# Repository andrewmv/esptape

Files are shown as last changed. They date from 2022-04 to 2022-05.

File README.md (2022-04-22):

An ESPHome based Home Assistant integration for controlling a Sony TC-WE675 Tape deck over its A1 Control serial port.

Would probably work on other Sony A1 tape decks, and could likely be expanded to support other Sony A1 audio equipment.

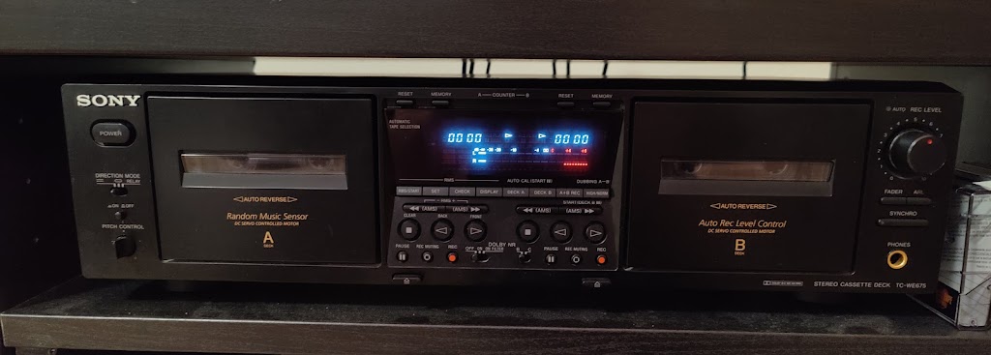
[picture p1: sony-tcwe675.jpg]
sony-tcwe675


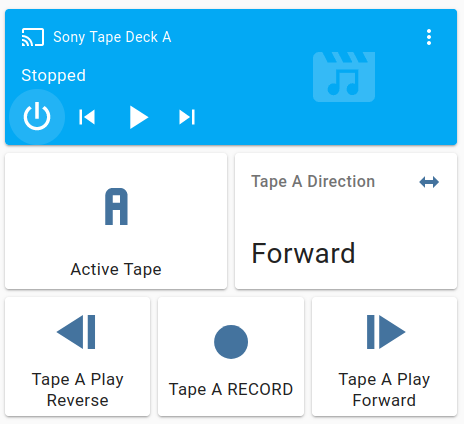
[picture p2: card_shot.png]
card_shot


## Repository Structure

* /esphome - esphome YAML code
* /homeassistant - sample HACS/media_player_template entity and lovelace cards
* /util - code timing conversion utilities
* /pcb - EagleCAD files for hardware build
* /enclosure - OpenSCAD and STL files for 3D printing enclosure

## Protocol 

Protocol based in part on the A1/S-Link reverse engineering work of:

http://cegt201.bradley.edu/projects/proj2001/sonyntwk/SLink.PDF

and:

http://web.archive.org/web/20040722145551/http://www.undeadscientist.com/slink/encoding.html

I created a PulseView / Sigrok logic analyizer plugin to aid in the discovery of device specific codes:

https://github.com/andrewmv/sony-a1-sigrok-pd

## Status Codes

Reported from the device and interpreted by ESPHome

| Address | Code | Meaning | Notes |
| --- | ---- | --- | --- |
| 0xAC | 0x00 | Tape B Play | No indication of direction is provided |
| 0xAC | 0x01 | Tape B Stop | |
| 0xAC | 0x02 | Tape B Pause | |
| 0xAC | 0x04 | Tape B Record | Recording started |
| 0xAC | 0x05 | Tape B Eject | |
| 0xAC | 0x06 | Tape B Autoreverse | Valid only from Play. Playback has reached end of side, but will continue on other side or deck. Always followed by a Stop, then a Play from the appropriate deck |
| 0xAC | 0x07 | Tape B Cue | |
| 0xAC | 0x08 | Tape B Insert | |
| 0xAC | 0x0a | End of Tape B | End of side reached, no followup playback will happen. Valid from Play, RR, FF, or AMS. |
| 0xAC | 0x40 | Tape A Play | No indication of direction is provided |
| 0xAC | 0x41 | Tape A Stop | |
| 0xAC | 0x42 | Tape A Pause | |
| 0xAC | 0x44 | Tape A Record | Recording started |
| 0xAC | 0x45 | Tape A Eject | |
| 0xAC | 0x46 | Tape A Autoreverse | Valid only from Play. Playback has reached end of side, but will continue on other side or deck. Always followed by a Stop, then a Play from the appropriate deck |
| 0xAC | 0x47 | Tape A Cue | Recording cued, play not yet pressed |
| 0xAC | 0x48 | Tape A Insert | |
| 0xAC | 0x4a | End of Tape A | End of side reached, no followup playback will happen. Valid from Play, RR, FF, or AMS. |

## Command codes

Sent to and interpreted by the device

| Address | Command | Result |
| --- | --- | --- |
| 0xA4 | 0x00 | Deck B Play (Current Direction) |
| 0xA4 | 0x01 | Deck B Stop |
| 0xA4 | 0x02 | Deck B Pause (Fixed) |
| 0xA4 | 0x03 | Deck B Pause (Toggle) |
| 0xA4 | 0x04 | Deck B Rec (Current Direction) |
| 0xA4 | 0x07 | Deck B Rec Cue (Direction Selectable with subsequent Play) |
| 0xA4 | 0x0A | Deck B FF (While Stopped – Forward) / AMS (While Playing – Current Direction) |
| 0xA4 | 0x0B | Deck B RR (While Stopped – Reverse) / AMS (While Playing – Current Direction) |
| 0xA4 | 0x0C | Deck B Play Forward |
| 0xA4 | 0x0D | Deck B Play Backward |
| 0xA4 | 0x40 | Deck A Play (Current Direction) |
| 0xA4 | 0x41 | Deck A Stop |
| 0xA4 | 0x42 | Deck A Pause (Fixed) |
| 0xA4 | 0x43 | Deck A Pause (Toggle) |
| 0xA4 | 0x44 | Deck A Rec (Current Direction) |
| 0xA4 | 0x47 | Deck A Rec Cue |
| 0xA4 | 0x4A | Deck A FF (While Stopped – Forward) / AMS (While Playing – Current Direction) |
| 0xA4 | 0x4B | Deck A RR (While Stopped – Rewind) / AMS (While Playing – Current Direction) |
| 0xA4 | 0x4C | Deck A Play Forward |
| 0xA4 | 0x4D | Deck A Play Backward |

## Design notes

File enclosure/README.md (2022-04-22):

OpenSCAD source files and rendered STLs for printable PCB enclosure.

Designed to use M2 x 3.5mm threaded brass inserts

## Print Settings

* Supports: no
* Infill: 100% where tape_enclosure and tape_enclosure_supports overlap, 20% everywhere else
* Material: any

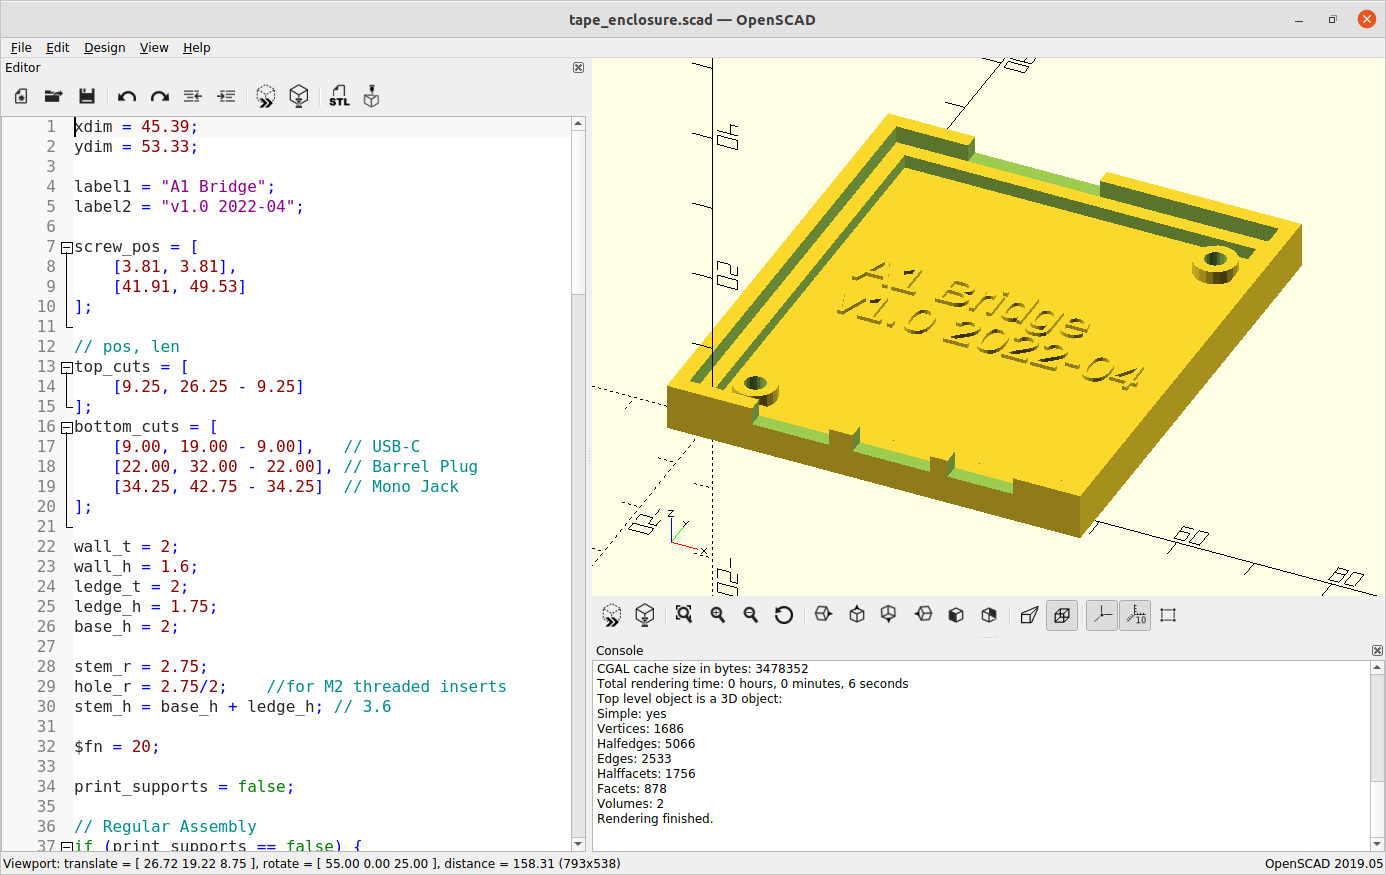
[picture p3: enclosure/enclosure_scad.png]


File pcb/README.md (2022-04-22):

Board and schematic files for EagleCAD

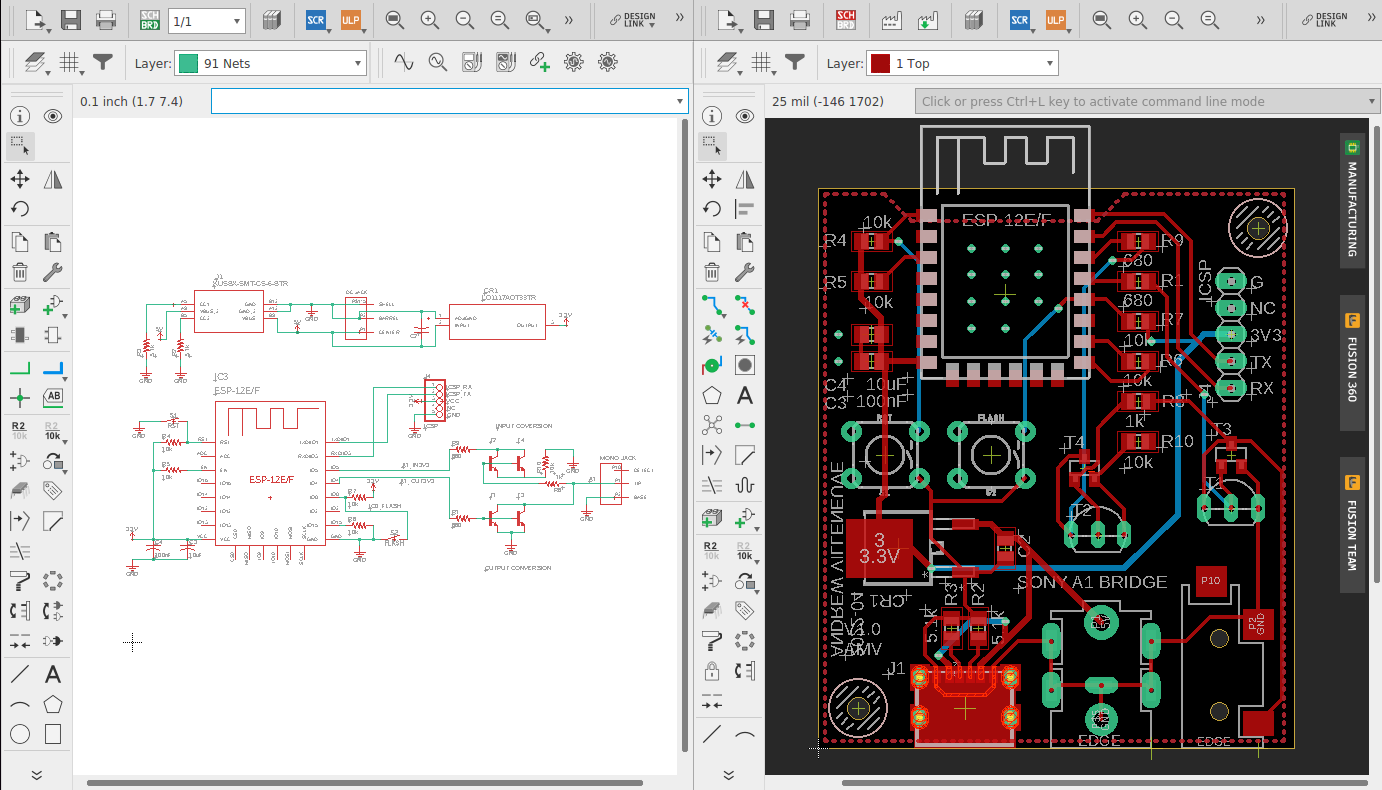
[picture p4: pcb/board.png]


## BOM

| Part | Description | Qty  | Link |
| --- | --- | ---- | --- |
| KUSBX-SMT-CS-6-BTR | 6-pin USB-C power port | 1 | https://www.digikey.com/en/products/detail/kycon-inc/KUSBX-SMT-CS-6-BTR/13545035 |
| ...Or
| PJ-082BH | 5mm DC barrel blug | 1 | https://www.digikey.com/en/products/detail/cui-devices/PJ-082BH/3477156 |
| MJ-3523-SMT-TR | 3.5mm mono jack | 1 | https://www.digikey.com/en/products/detail/cui-devices/MJ-3523-SMT-TR/281296 |
| MMBT2222A-G | SOT-23 NPN BJT | 2 | https://www.digikey.com/en/products/detail/comchip-technology/MMBT2222A-G/3300110 |
| ...Or
| 2N2222 | TO-92 NPN BTJ | 2 | |
| TS02-66-60-BK-100-LCR-D | Tactile switch | 2 | https://www.digikey.com/en/products/detail/cui-devices/TS02-66-60-BK-100-LCR-D/15634327 |
| | 0805 100nF Capacitor | 2 | |
| | 0805 10k Resistor | 5 | |
| | 0805 10uF Capacitor | 1 | |
| | 0805 1k Resistor | 1 | |
| | 0805 5.1k Resistor | 2 | |
| | 0805 680 ohm Resistor  | 2 | |
| ESP8266-12F | ESP Module | 1 | https://www.amazon.com/gp/product/B089PTN2V5/ |
| LD1117ADT33TR | 3.3V Linear Regulator  | 1 | https://www.digikey.com/en/products/detail/stmicroelectronics/LD1117ADT33TR/669253 |
| | 5x2.54mm header | 1 | |

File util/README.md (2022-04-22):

# Utilities

Quick and dirty development tools with no input checking. You have been warned.

## code_cv.py

Convert Sony A1 code in Hex format to esphome remote_transmitter.transmit_raw timing blocks.
Do not provide a leading '0x'

Example: 

	code_cv.py ac40
	[ 2400, -600, 1200, -600, 600, -600, 1200, -600, 600, -600, 1200, -600, 1200, -600, 600, -600, 600, -600, 600, -600, 1200, -600, 600, -600, 600, -600, 600, -600, 600, -600, 600, -600, 600 ]

## rev_code_cv.py

Convert an esphome remote_receiver.receive_raw log message block into a Sony A1 code.

Example:

	./rev_code_cv.py "[22:06:27][D][remote.raw:041]: Received Raw: 2418, -594, 1202, -594, 603, -595, 1201, -596, 602, -597, 1200, -594, 1202, -595, 603, -594, 603, -597, 600, -598, 1199, -595, 602, -599, 599, -595, 1202, -594, 604, -594, 602, -596, 602"
	0xac
	0x48

## a1_rs232_bridge.ino

An Arduino sketch for code scanning and discovery. Should support any 5V tolerant target board.

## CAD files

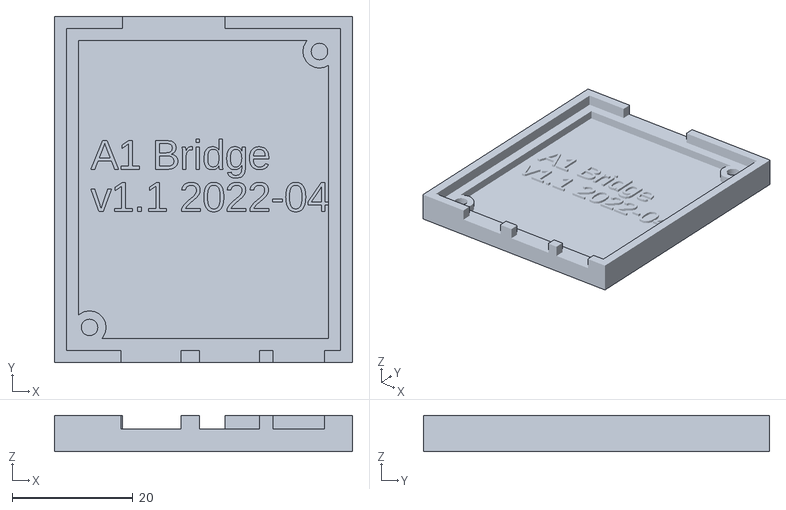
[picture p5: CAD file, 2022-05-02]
enclosure/tape_enclosure.stl
49.4 x 57.3 x 6.00

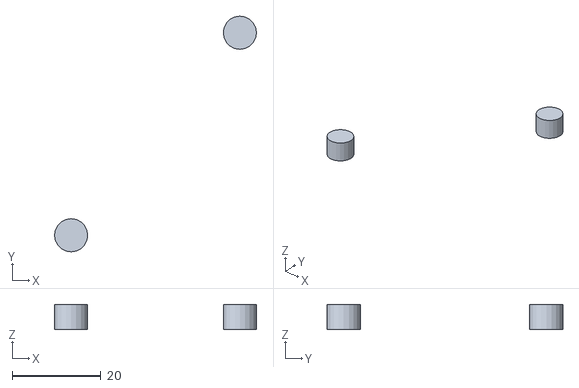
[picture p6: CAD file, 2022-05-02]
enclosure/tape_enclosure_supports.stl
45.6 x 53.2 x 5.75

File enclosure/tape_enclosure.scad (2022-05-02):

xdim = 45.39;
ydim = 53.33;

label1 = "A1 Bridge";
label2 = "v1.1 2022-04";

screw_pos = [
    [3.81, 3.81],
    [41.91, 49.53]
];

// pos, len
top_cuts = [
    [9.25, 26.25 - 9.25]
];
bottom_cuts = [
    [9.00, 19.00 - 9.00],   // USB-C
    [22.00, 32.00 - 22.00], // Barrel Plug
    [34.25, 42.75 - 34.25]  // Mono Jack
];

wall_t = 2;
wall_h = 1.6;
ledge_t = 2;
ledge_h = 1.75;
base_h = 2;

stem_r = 2.75;	
hole_r = 2.75/2;	//for M2 threaded inserts
stem_h = base_h + ledge_h; // 3.6

$fn = 20;

print_supports = false;

// Regular Assembly
if (print_supports == false) {
    color("white") base();
    color("pink") ledge();
    difference() {
        color("red") wall();
        color("blue") cuts();
    }

    // Labels
    text_x = 4.0;
    text_y = 30;
    text_z = base_h;
    translate([text_x, text_y, text_z]) {
        linear_extrude(0.5) {
            text(label1, size=5);
        }
    }
    translate([text_x, text_y - 7, text_z]) {
        linear_extrude(0.5) {
            text(label2, size=5);
        }
    }
    // Mounting Stems
    for (i = [0:len(screw_pos)-1]) {
        translate(screw_pos[i]) {
            mounting_stem();
     }
}

} else {
    // Support Assembly
    for (i = [0:len(screw_pos)-1]) {
        translate(screw_pos[i]) {
            cylinder(r=stem_r + 1, h=stem_h+2);
        }
    }
}




// Modules

module base() {
    difference() {
        cube(size=[xdim, ydim, base_h]);
        for (i = [0:len(screw_pos)-1]) {
            translate(screw_pos[i])
                cylinder(r=stem_r, h=10);
        }
    }
}

module ledge() {
    xt = ledge_t;
    yt = ledge_t;
    xs = xdim - (2 * ledge_t);
    ys = ydim - (2 * ledge_t);
    zs = base_h + ledge_h;
    difference() {
        cube(size=[xdim, ydim, zs]);
        translate([xt, yt, 0])
            cube(size=[xs, ys, 10]);
    } 
}

module wall() {
    xt = -wall_t;
    yt = -wall_t;
    xs = xdim + (2 * wall_t);
    ys = ydim + (2 * wall_t);
    zs = base_h + ledge_t + wall_t;
    difference() {
        translate([xt, yt, 0])
            cube(size=[xs, ys, zs]);
        translate([0, 0, 0])
            cube(size=[xdim, ydim, 10]);
    }
}

module mounting_stem() {
	difference() {
		linear_extrude(stem_h) {
			circle(stem_r);
		}
		translate([0,0,0.25]) {
			linear_extrude(stem_h + 1) {
				circle(hole_r);
			}
		}
	}
}

module cuts() {
    // bottom cuts
    yt = -wall_t - 1;
    xt = 0;
    zt = base_h + ledge_h;
    translate([xt, yt, zt]) {
        for (i = [0:len(bottom_cuts)-1]) {
            translate([bottom_cuts[i][0], 0, 0]) {
                cube(size=[bottom_cuts[i][1],wall_t + 2, wall_h + 1]);
            }
        }
    }
    // top cuts
    yt2 = ydim - 1;
    translate([xt, yt2, zt]) {
        for (i = [0:len(top_cuts)-1]) {
            translate([top_cuts[i][0], 0, 0]) {
                cube(size=[top_cuts[i][1], wall_t + 2, wall_h + 1]);
            }
        }
    }
}

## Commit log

2022-04-22 Added Enclosure
    [tape_enclosure.scad]
2022-04-22 Reorg directory structure, add screenshot
    [tape_enclosure.scad, tape_enclosure.stl, tape_enclosure_supports.stl]
2022-04-22 Added EagleCAD files, staged README
    [8266_a1_bridge_v1.brd, 8266_a1_bridge_v1.sch]
2022-04-22 Updated docs, resources
    [TC-WE675 Codes.ods]
2022-04-22 Enclosure and PCB pictures
2022-04-22 Added BOM
    [bom.ods]
2022-05-02 Enclosure fixes
    [tape_enclosure.scad, tape_enclosure.stl, tape_enclosure_supports.stl]
2022-05-02 Updated pin mapping for 12F module
2022-10-23 Disabled status LED
